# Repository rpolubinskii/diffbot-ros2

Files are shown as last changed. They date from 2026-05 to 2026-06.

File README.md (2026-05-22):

# DiffBot

ROS 2 Humble package for a physical differential-drive robot with:

- custom `ros2_control` hardware interface
- RealSense RGB-D camera
- RPLidar
- RTAB-Map SLAM
- Nav2
- wheel odometry, camera IMU, and external ICM-20948 IMU

## Build

```bash
source /opt/ros/humble/setup.bash
cd ros2_ws
rosdep install --from-paths . --ignore-src -r -y
colcon build --packages-select diffbot
source install/setup.bash
```

## Run On The Robot

The full launch expects the robot hardware and these device names:

- `/dev/imu-encoder-node`
- `/dev/motor-controller`
- `/dev/rplidar`

Run:

```bash
source /opt/ros/humble/setup.bash
cd ros2_ws
source install/setup.bash
ros2 launch diffbot diffbot.launch.py
```

## Firmware And Udev

Firmware lives in `embedded/`:

- `imu-encoder-node/` publishes encoder ticks, IMU, and magnetometer data.
- `motor-controller/` receives serial PWM commands.

The helper scripts in `embedded/` are for the target robot host. They may upload
firmware, run `git pull`, or write udev rules with `sudo`, so review them before
running on another machine.

## License

Apache-2.0. See `LICENSE`.

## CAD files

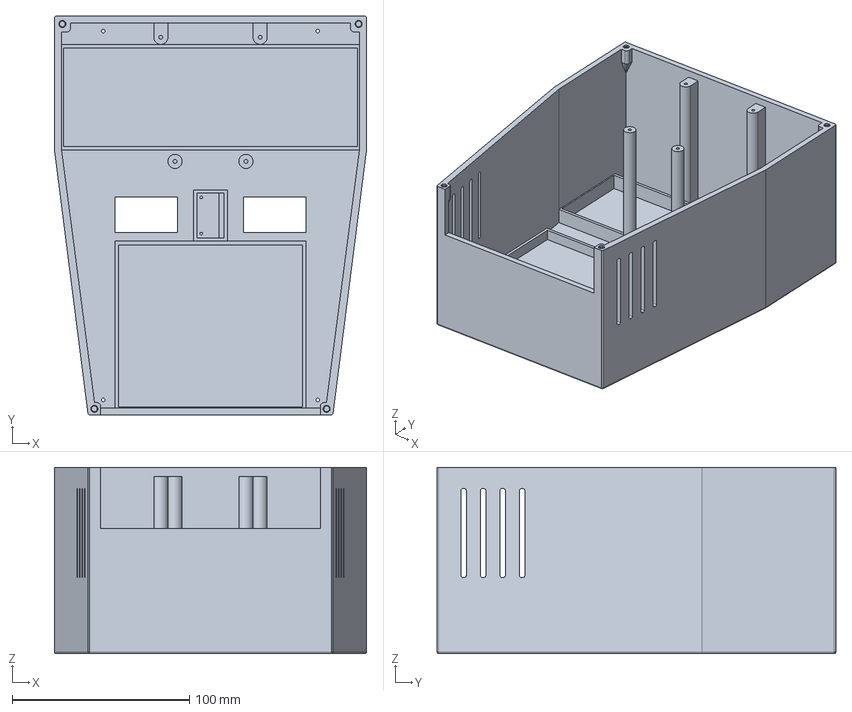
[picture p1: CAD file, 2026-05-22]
cad/Main Compartment.FCStd
176.0 x 225.0 x 105.0 mm

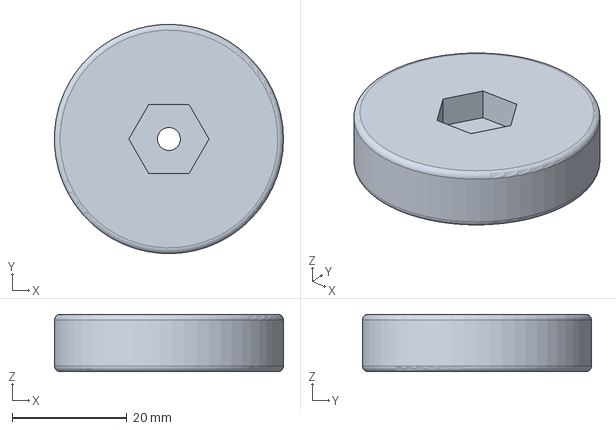
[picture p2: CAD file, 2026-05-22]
cad/Wheel Mount.FCStd
40.0 x 40.0 x 10.0 mm

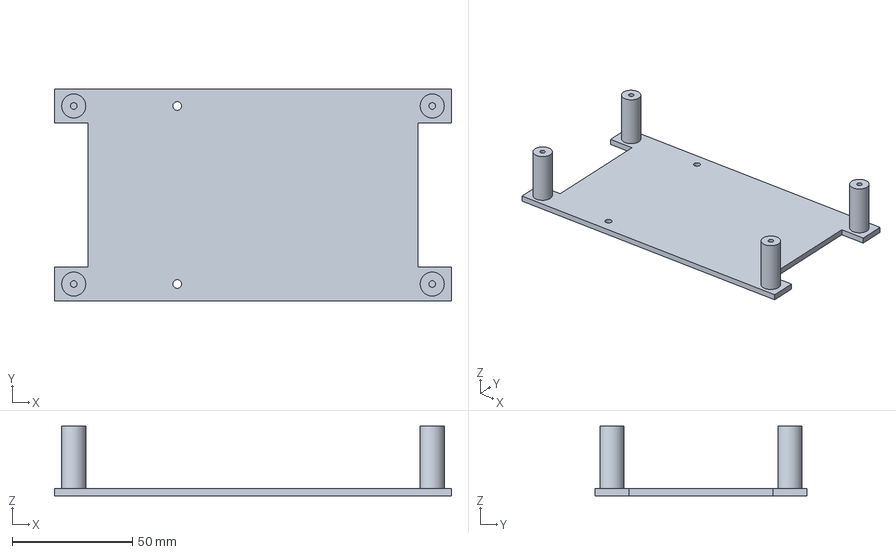
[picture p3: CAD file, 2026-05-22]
cad/Battery Pack Spacer.FCStd
165.0 x 88.0 x 29.0 mm

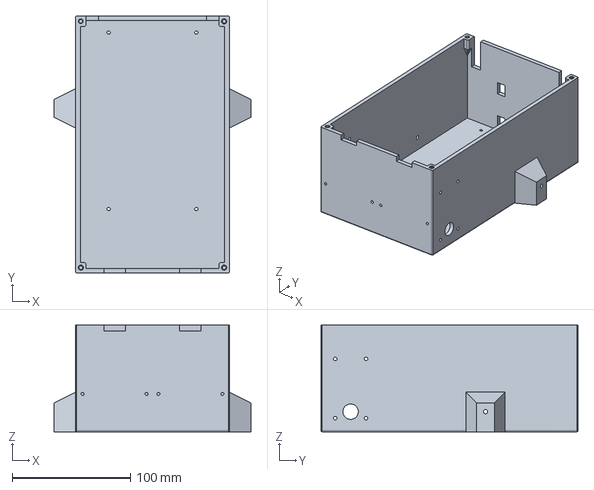
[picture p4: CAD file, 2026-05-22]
cad/Engine Compartment.FCStd
166.0 x 217.0 x 90.0 mm

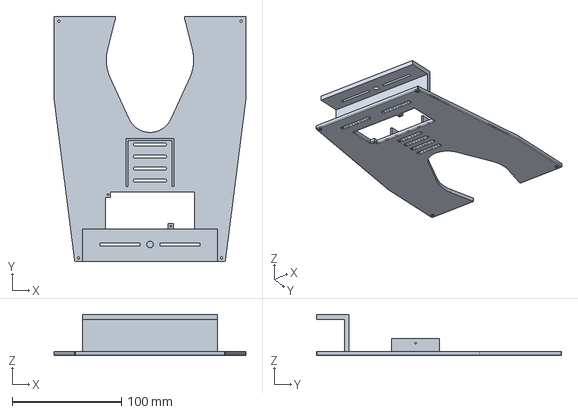
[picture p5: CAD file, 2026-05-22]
cad/Lid.FCStd
176.0 x 225.0 x 38.0 mm

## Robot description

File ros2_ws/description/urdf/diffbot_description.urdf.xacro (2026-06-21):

<?xml version="1.0"?>
<robot xmlns:xacro="http://www.ros.org/wiki/xacro">

  <xacro:macro name="diffbot" params="prefix">

    <xacro:property name="PI" value="3.1415926535897931"/>
    <xacro:property name="base_mass" value="3.4"/>
    <xacro:property name="base_width" value="0.24"/>
    <xacro:property name="base_length" value="0.13"/>
    <xacro:property name="base_length_collision" value="0.23"/>
    <xacro:property name="base_height" value="0.2"/>
    <xacro:property name="wheel_x_offset" value="0.0265"/>
    <xacro:property name="wheel_z_offset" value="0.1"/>
    <xacro:property name="wheel_separation" value="0.2"/>
    <xacro:property name="wheel_mass" value="0.3"/>
    <xacro:property name="wheel_len" value="0.030"/>
    <xacro:property name="wheel_radius" value="0.036"/>
    <xacro:property name="z_offset" value="-${base_height/2}"/>

    <link name="base_footprint">
      <visual>
        <origin xyz="0 0 0" rpy="0 0 0"/>
        <geometry>
          <box size="0.01 0.01 0.005"/>
        </geometry>
        <material name="green"/>
      </visual>
    </link>

    <link name="${prefix}base_link">
      <visual>
        <origin xyz="0 0 0" rpy="0 0 0"/>
        <geometry>
          <box size="0.01 0.01 0.005"/>
        </geometry>
        <material name="blue"/>
      </visual>

      <inertial>
        <origin xyz="0 0 0" rpy="0 0 0"/>
        <mass value="${base_mass}"/>
        <inertia ixx="${base_mass / 12.0 * (base_length*base_length + base_height*base_height)}" ixy="0.0" ixz="0.0" iyy="${base_mass / 12.0 * (base_height*base_height + base_width*base_width)}" iyz="0.0" izz="${base_mass / 12.0 * (base_width*base_width + base_length*base_length)}"/>
      </inertial>

      <visual>
        <origin xyz="0 0 0" rpy="0 0 0"/>
        <geometry>
          <box size="${base_width} ${base_length} ${base_height}"/>
        </geometry>
        <material name="orange"/>
      </visual>

      <collision>
        <origin xyz="0 0 0" rpy="0 0 0"/>
        <geometry>
          <box size="${base_width} ${base_length_collision} ${base_height}"/>
        </geometry>
      </collision>
    </link>

    <joint name="base_footprint_joint" type="fixed">
      <parent link="base_footprint"/>
      <child link="base_link"/>
      <origin xyz="0 0 ${base_height / 2 + wheel_radius}" rpy="0 0 0"/>
    </joint>

    <joint name="${prefix}left_wheel_joint" type="continuous">
      <parent link="${prefix}base_link"/>
      <child link="${prefix}left_wheel"/>
      <origin xyz="${wheel_x_offset} -${wheel_separation/2} -${wheel_z_offset}" rpy="0 0 0"/>
      <axis xyz="0 1 0"/>
      <dynamics damping="0.2"/>
      <limit effort="100" velocity="1.0"/>
    </joint>

    <link name="${prefix}left_wheel">
      <collision>
        <origin xyz="0 0 0" rpy="${PI/2} 0 0"/>
        <geometry>
          <cylinder length="${wheel_len}" radius="${wheel_radius}"/>
        </geometry>
      </collision>

      <visual>
        <origin xyz="0 0 0" rpy="${PI/2} 0 0"/>
        <geometry>
          <cylinder length="${wheel_len}" radius="${wheel_radius}"/>
        </geometry>
        <material name="black"/>
      </visual>

      <inertial>
        <origin xyz="0 0 0" rpy="${PI/2} 0 0"/>
        <mass value="${wheel_mass}"/>
        <inertia ixx="${wheel_mass / 12.0 * (3*wheel_radius*wheel_radius + wheel_len*wheel_len)}" ixy="0.0" ixz="0.0" iyy="${wheel_mass / 12.0 * (3*wheel_radius*wheel_radius + wheel_len*wheel_len)}" iyz="0.0" izz="${wheel_mass / 2.0 * wheel_radius*wheel_radius}"/>
      </inertial>
    </link>

    <joint name="${prefix}right_wheel_joint" type="continuous">
      <parent link="${prefix}base_link"/>
      <child link="${prefix}right_wheel"/>
      <origin xyz="${wheel_x_offset} ${wheel_separation/2} -${wheel_z_offset}" rpy="0 0 0"/>
      <axis xyz="0 1 0"/>
      <dynamics damping="0.2"/>
      <limit effort="100" velocity="1.0"/>
    </joint>

    <link name="${prefix}right_wheel">
      <collision>
        <origin xyz="0 0 0" rpy="${PI/2} 0 0"/>
        <geometry>
          <cylinder length="${wheel_len}" radius="${wheel_radius}"/>
        </geometry>
      </collision>

      <visual>
        <origin xyz="0 0 0" rpy="${PI/2} 0 0"/>
        <geometry>
          <cylinder length="${wheel_len}" radius="${wheel_radius}"/>
        </geometry>
        <material name="black"/>
      </visual>

      <inertial>
        <origin xyz="0 0 0" rpy="${PI/2} 0 0"/>
        <mass value="${wheel_mass}"/>
        <inertia ixx="${wheel_mass / 12.0 * (3*wheel_radius*wheel_radius + wheel_len*wheel_len)}" ixy="0.0" ixz="0.0" iyy="${wheel_mass / 12.0 * (3*wheel_radius*wheel_radius + wheel_len*wheel_len)}" iyz="0.0" izz="${wheel_mass / 2.0 * wheel_radius*wheel_radius}"/>
      </inertial>
    </link>

    <link name="scan">
      <visual>
        <geometry>
          <cylinder radius="0.035" length="0.02"/>
        </geometry>
        <origin xyz="0 0 0" rpy="0 0 0"/>
        <material name="black"/>
      </visual>
    </link>

    <joint name="laser_joint" type="fixed">
      <parent link="base_link"/>
      <child link="scan"/>
      <origin xyz="-0.0725 0 0.11" rpy="0 0 0"/>
    </joint>

    <link name="camera_link">
      <visual>
        <origin xyz="0 0 0" rpy="0 0 0"/>
        <geometry>
          <box size="0.03 ${base_length} 0.03"/>
        </geometry>
        <material name="black"/>
      </visual>
    </link>

    <joint name="camera_joint" type="fixed">
      <parent link="base_link"/>
      <child link="camera_link"/>
      <origin xyz="0.105 0 0.085" rpy="0 0 0"/>
    </joint>

    <link name="imu_link">
      <visual>
        <origin xyz="0 0 0" rpy="0 0 0"/>
        <geometry>
          <box size="0.01 0.01 0.005"/>
        </geometry>
        <material name="red"/>
      </visual>
    </link>

    <joint name="imu_joint" type="fixed">
      <parent link="base_link"/>
      <child link="imu_link"/>
      <origin xyz="0 0 -0.005" rpy="0 0 -${PI/2}"/>
    </joint>

  </xacro:macro>

</robot>

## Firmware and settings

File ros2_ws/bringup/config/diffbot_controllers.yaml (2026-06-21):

controller_manager:
  ros__parameters:
    update_rate: 50

    joint_state_broadcaster:
      type: joint_state_broadcaster/JointStateBroadcaster

    diffbot_base_controller:
      type: diff_drive_controller/DiffDriveController

diffbot_base_controller:
  ros__parameters:
    left_wheel_names: ["left_wheel_joint"]
    right_wheel_names: ["right_wheel_joint"]

    wheel_separation: 0.2
    wheels_per_side: 1
    wheel_radius: 0.036

    wheel_separation_multiplier: 1.190
    left_wheel_radius_multiplier: 1.0611
    right_wheel_radius_multiplier: 1.0611

    publish_rate: 50.0
    base_frame_id: base_footprint
    odom_frame_id: odom
    pose_covariance_diagonal : [0.001, 0.001, 0.001, 0.001, 0.001, 0.01]
    twist_covariance_diagonal: [0.001, 0.001, 0.001, 0.001, 0.001, 0.01]

    use_stamped_vel: false
    open_loop: false
    position_feedback: true
    cmd_vel_timeout: 0.5
    enable_odom_tf: false

    linear.x.has_velocity_limits: false
    linear.x.has_acceleration_limits: false
    linear.x.has_jerk_limits: false
    linear.x.max_velocity: 1.0
    linear.x.min_velocity: -1.0
    linear.x.max_acceleration: 1.0
    linear.x.max_jerk: 0.0
    linear.x.min_jerk: 0.0

    angular.z.has_velocity_limits: false
    angular.z.has_acceleration_limits: false
    angular.z.has_jerk_limits: false
    angular.z.max_velocity: 1.0
    angular.z.min_velocity: -1.0
    angular.z.max_acceleration: 1.0
    angular.z.min_acceleration: -1.0
    angular.z.max_jerk: 0.0
    angular.z.min_jerk: 0.0

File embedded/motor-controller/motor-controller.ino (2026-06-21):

#define PWMA  D5   // GPIO14
#define AIN1  D1   // GPIO5
#define AIN2  D2   // GPIO4

#define PWMB  D6   // GPIO12
#define BIN1  D7   // GPIO13
#define BIN2  D0   // GPIO16

#define STBY  D8   // GPIO15 (must be LOW at boot!)

const int pwmFreq = 1000;
const int pwmRange = 1023;
const int serialBaud = 115200;
const unsigned long commandTimeoutMs = 300;
const unsigned long stbyRecoveryPulseMs = 20;
const int pwmMaxAbs = 1023;

unsigned long lastValidCommandMs = 0;
bool timedOut = false;
bool stbyRecoveryPending = false;

void stopAllMotors();
void setStandby(bool enabled);
void maybeHandleTimeout();
void handleSerialInput();
bool parseCommand(const char* line, int &speedL, int &speedR);
int clampPwm(int speed);
void applyMotorCommands(int speedL, int speedR);

void setup() {
  pinMode(PWMA, OUTPUT);
  pinMode(AIN1, OUTPUT);
  pinMode(AIN2, OUTPUT);
  pinMode(PWMB, OUTPUT);
  pinMode(BIN1, OUTPUT);
  pinMode(BIN2, OUTPUT);
  pinMode(STBY, OUTPUT);

  analogWriteFreq(pwmFreq);
  analogWriteRange(pwmRange);

  setStandby(true);
  stopAllMotors();

  Serial.begin(serialBaud);
  Serial.setTimeout(10);
  lastValidCommandMs = millis();
}

void loop() {
  handleSerialInput();
  maybeHandleTimeout();
}

void setStandby(bool enabled) {
  digitalWrite(STBY, enabled ? HIGH : LOW);
}

void stopAllMotors() {
  motorA(0);
  motorB(0);
}

void maybeHandleTimeout() {
  const unsigned long now = millis();
  if (!timedOut && (now - lastValidCommandMs > commandTimeoutMs)) {
    stopAllMotors();
    timedOut = true;
    stbyRecoveryPending = true;
  }
}

void handleSerialInput() {
  static char line[32];
  static size_t idx = 0;

  while (Serial.available() > 0) {
    const char c = static_cast<char>(Serial.read());

    if (c == '\r') {
      continue;
    }

    if (c == '\n') {
      line[idx] = '\0';
      idx = 0;

      int speedL = 0;
      int speedR = 0;
      if (!parseCommand(line, speedL, speedR)) {
        continue;
      }

      if (stbyRecoveryPending) {
        setStandby(false);
        delay(stbyRecoveryPulseMs);
        setStandby(true);
        stbyRecoveryPending = false;
      }

      applyMotorCommands(speedL, speedR);
      lastValidCommandMs = millis();
      timedOut = false;
      continue;
    }

    if (idx < sizeof(line) - 1) {
      line[idx++] = c;
    } else {
      idx = 0;
    }
  }
}

bool parseCommand(const char* line, int &speedL, int &speedR) {
  return sscanf(line, "%d,%d", &speedL, &speedR) == 2;
}

int clampPwm(int speed) {
  if (speed > pwmMaxAbs) return pwmMaxAbs;
  if (speed < -pwmMaxAbs) return -pwmMaxAbs;
  return speed;
}

void applyMotorCommands(int speedL, int speedR) {
  motorA(clampPwm(speedL));
  motorB(clampPwm(speedR));
}


void motorA(int speed) {
  if (speed > 0) {
    digitalWrite(AIN1, HIGH);
    digitalWrite(AIN2, LOW);
    analogWrite(PWMA, speed);
  } else if (speed < 0) {
    digitalWrite(AIN1, LOW);
    digitalWrite(AIN2, HIGH);
    analogWrite(PWMA, abs(speed));
  } else {
    digitalWrite(AIN1, LOW);
    digitalWrite(AIN2, LOW);
    analogWrite(PWMA, 0);
  }
}

void motorB(int speed) {
  if (speed > 0) {
    digitalWrite(BIN1, HIGH);
    digitalWrite(BIN2, LOW);
    analogWrite(PWMB, speed);
  } else if (speed < 0) {
    digitalWrite(BIN1, LOW);
    digitalWrite(BIN2, HIGH);
    analogWrite(PWMB, abs(speed));
  } else {
    digitalWrite(BIN1, LOW);
    digitalWrite(BIN2, LOW);
    analogWrite(PWMB, 0);
  }
}

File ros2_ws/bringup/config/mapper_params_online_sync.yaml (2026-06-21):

slam_toolbox:
  ros__parameters:

    solver_plugin: solver_plugins::CeresSolver
    ceres_linear_solver: SPARSE_NORMAL_CHOLESKY
    ceres_preconditioner: SCHUR_JACOBI
    ceres_trust_strategy: LEVENBERG_MARQUARDT
    ceres_dogleg_type: TRADITIONAL_DOGLEG
    ceres_loss_function: None

    odom_frame: odom
    map_frame: map
    base_frame: base_footprint
    scan_topic: /scan
    use_map_saver: true
    mode: mapping

    debug_logging: false
    throttle_scans: 1
    transform_publish_period: 0.02
    map_update_interval: 5.0
    resolution: 0.05
    min_laser_range: 0.2
    max_laser_range: 12.0
    minimum_time_interval: 0.5
    transform_timeout: 0.2
    tf_buffer_duration: 30.
    stack_size_to_use: 40000000
    enable_interactive_mode: true

    use_scan_matching: true
    use_scan_barycenter: true
    minimum_travel_distance: 0.5
    minimum_travel_heading: 0.5
    scan_buffer_size: 10
    scan_buffer_maximum_scan_distance: 10.0
    link_match_minimum_response_fine: 0.1
    link_scan_maximum_distance: 1.5
    loop_search_maximum_distance: 3.0
    do_loop_closing: true
    loop_match_minimum_chain_size: 10
    loop_match_maximum_variance_coarse: 3.0
    loop_match_minimum_response_coarse: 0.35
    loop_match_minimum_response_fine: 0.45

    correlation_search_space_dimension: 0.5
    correlation_search_space_resolution: 0.01
    correlation_search_space_smear_deviation: 0.1

    loop_search_space_dimension: 8.0
    loop_search_space_resolution: 0.05
    loop_search_space_smear_deviation: 0.03

    distance_variance_penalty: 0.5
    angle_variance_penalty: 1.0

    fine_search_angle_offset: 0.00349
    coarse_search_angle_offset: 0.349
    coarse_angle_resolution: 0.0349
    minimum_angle_penalty: 0.9
    minimum_distance_penalty: 0.5
    use_response_expansion: true
    min_pass_through: 2
    occupancy_threshold: 0.1

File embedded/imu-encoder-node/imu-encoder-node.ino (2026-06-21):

#include <Arduino.h>
#include <Wire.h>
#include <ICM_20948.h>

// D1/D2/D5/D6 are already used.
constexpr uint8_t I2C_SDA_PIN = D7;
constexpr uint8_t I2C_SCL_PIN = D4;

// AD0 low selects 0x68.
constexpr bool kImuAd0High = false;
constexpr uint32_t kPublishPeriodMs = 10;
constexpr uint32_t kMinEncoderPulseUs = 200;
constexpr uint16_t kGyroCalibrationSamples = 800;
constexpr uint32_t kGyroCalibrationWarmupMs = 3000;
constexpr float kMilliGToG = 1.0f / 1000.0f;

struct ImuSample {
  float ax_g;
  float ay_g;
  float az_g;
  float gx_dps;
  float gy_dps;
  float gz_dps;
  float mx_ut;
  float my_ut;
  float mz_ut;
};

struct GyroBias {
  float x_dps;
  float y_dps;
  float z_dps;
};

ICM_20948_I2C imu;
static GyroBias gyroBias = {0.0f, 0.0f, 0.0f};
static bool imuConfigured = false;

// ESP8266 GPIO numbers.
const byte encoderLPinA = 5;
const byte encoderLPinB = 4;
const byte encoderRPinA = 14;
const byte encoderRPinB = 12;

volatile int pulseL = 0;
volatile int pulseR = 0;
volatile uint32_t lastL = 0;
volatile uint32_t lastR = 0;

bool imuInit() {
  imu.begin(Wire, kImuAd0High);
  if (imu.status != ICM_20948_Stat_Ok) {
    Serial.print("IMU init failed: ");
    Serial.println(imu.statusString());
    return false;
  }

  return true;
}

bool readImu(ImuSample &sample) {
  imu.getAGMT();
  if (imu.status != ICM_20948_Stat_Ok) {
    return false;
  }

  sample.ax_g = imu.accX() * kMilliGToG;
  sample.ay_g = imu.accY() * kMilliGToG;
  sample.az_g = imu.accZ() * kMilliGToG;
  sample.gx_dps = imu.gyrX() - gyroBias.x_dps;
  sample.gy_dps = imu.gyrY() - gyroBias.y_dps;
  sample.gz_dps = imu.gyrZ() - gyroBias.z_dps;
  sample.mx_ut = imu.magX();
  sample.my_ut = imu.magY();
  sample.mz_ut = imu.magZ();
  return true;
}

bool calibrateGyro(uint16_t samples) {
  float sx = 0.0f;
  float sy = 0.0f;
  float sz = 0.0f;
  uint16_t collected = 0;
  uint32_t attempts = 0;

  while (collected < samples && attempts < samples * 20U) {
    ++attempts;
    if (!imu.dataReady()) {
      delay(5);
      continue;
    }

    imu.getAGMT();
    if (imu.status != ICM_20948_Stat_Ok) {
      return false;
    }

    sx += imu.gyrX();
    sy += imu.gyrY();
    sz += imu.gyrZ();
    ++collected;
    delay(5);
  }

  if (collected == 0) {
    return false;
  }

  gyroBias.x_dps = sx / static_cast<float>(collected);
  gyroBias.y_dps = sy / static_cast<float>(collected);
  gyroBias.z_dps = sz / static_cast<float>(collected);
  return collected == samples;
}

void IRAM_ATTR lISR() {
  const uint32_t now = micros();
  if (now - lastL < kMinEncoderPulseUs) {
    return;
  }
  lastL = now;

  if (digitalRead(encoderLPinB)) {
    pulseL--;
  } else {
    pulseL++;
  }
}

void IRAM_ATTR rISR() {
  const uint32_t now = micros();
  if (now - lastR < kMinEncoderPulseUs) {
    return;
  }
  lastR = now;

  if (digitalRead(encoderRPinB)) {
    pulseR++;
  } else {
    pulseR--;
  }
}

void setup() {
  Serial.begin(115200);
  delay(200);

  Wire.begin(I2C_SDA_PIN, I2C_SCL_PIN);
  Wire.setClock(400000);

  pinMode(encoderLPinB, INPUT_PULLUP);
  pinMode(encoderRPinB, INPUT_PULLUP);
  pinMode(encoderLPinA, INPUT_PULLUP);
  pinMode(encoderRPinA, INPUT_PULLUP);

  attachInterrupt(digitalPinToInterrupt(encoderLPinA), lISR, RISING);
  attachInterrupt(digitalPinToInterrupt(encoderRPinA), rISR, RISING);

  Serial.println("ICM-20948 IMU init...");
  imuConfigured = imuInit();
  if (!imuConfigured) {
    Serial.println("IMU init failed. Check wiring/address.");
    return;
  }

  Serial.println("IMU ready.");
  Serial.print("Waiting ");
  Serial.print(kGyroCalibrationWarmupMs);
  Serial.println(" ms before gyro calibration...");
  delay(kGyroCalibrationWarmupMs);
  Serial.println("Calibrating gyro... keep the board still.");
  if (!calibrateGyro(kGyroCalibrationSamples)) {
    Serial.println("Gyro calibration failed.");
    imuConfigured = false;
    return;
  }

  Serial.println("Gyro calibration done.");
  Serial.print("Gyro bias dps: ");
  Serial.print(gyroBias.x_dps, 4);
  Serial.print(", ");
  Serial.print(gyroBias.y_dps, 4);
  Serial.print(", ");
  Serial.println(gyroBias.z_dps, 4);
  Serial.println("Magnetometer ready via SparkFun library.");
}

void loop() {
  static uint32_t lastPublish = 0;
  const uint32_t now = millis();
  if (now - lastPublish < kPublishPeriodMs) {
    return;
  }
  lastPublish = now;

  int l = 0;
  int r = 0;
  noInterrupts();
  l = pulseL;
  r = pulseR;
  pulseL = 0;
  pulseR = 0;
  interrupts();

  if (!imuConfigured) {
    Serial.print(l);
    Serial.print(',');
    Serial.println(r);
    return;
  }

  ImuSample s{};
  if (!readImu(s)) {
    Serial.println("ERR_IMU");
    return;
  }

  // left_ticks,right_ticks,ax_g,ay_g,az_g,gx_dps,gy_dps,gz_dps,mx_uT,my_uT,mz_uT
  Serial.print(l);
  Serial.print(',');
  Serial.print(r);
  Serial.print(',');
  Serial.print(s.ax_g, 3);
  Serial.print(',');
  Serial.print(s.ay_g, 3);
  Serial.print(',');
  Serial.print(s.az_g, 3);
  Serial.print(',');
  Serial.print(s.gx_dps, 2);
  Serial.print(',');
  Serial.print(s.gy_dps, 2);
  Serial.print(',');
  Serial.print(s.gz_dps, 2);
  Serial.print(',');
  Serial.print(s.mx_ut, 2);
  Serial.print(',');
  Serial.print(s.my_ut, 2);
  Serial.print(',');
  Serial.println(s.mz_ut, 2);
}

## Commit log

2026-05-29 fix yaw drift
2026-06-03 add rplidar_motor.py to test motor switch
2026-06-04 build env fix
    [diffbot.ros2_control.xacro]
2026-06-04 lidar standby manager
2026-06-04 standby_scan relay
2026-06-04 wait for icp odometry to become healthy before nav goal execution
2026-06-04 Revert "wait for icp odometry to become healthy before nav goal execution"
    This reverts commit 29306980f660acc84309b33ac7d9d6acc7c210aa.
2026-06-04 add init timeout on lidar standby node
2026-06-21 RTAB-Map integration revision. (#1)
    [diffbot.materials.xacro, diffbot.urdf.xacro, diffbot_controllers.yaml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]
2026-06-22 Lower mapping-mode Nav2 linear velocity caps
    In mapping mode only, rewrite a temp Nav2 params file (via OpaqueFunction) to cap forward linear velocity at vx_max=0.35 m/s (from 0.75) and gentle the linear accel/decel (max_accel 0.4, max_decel -0.5). Localization mode passes the base nav2_params.yaml unchanged. Backward vx_min, rotational caps, the smoother deadband, and the hardware velocity->PWM tables are untouched, so the calibrated low-level mapping stays valid. Reduces motion blur / scan distortion while mapping.
    A further reduction to vx_max=0.25 (+ vx_std 0.1) was tested then reverted: no map-quality improvement over 0.35 and worse movement responsiveness.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
2026-06-28 initial_reset and lower fps for camera
